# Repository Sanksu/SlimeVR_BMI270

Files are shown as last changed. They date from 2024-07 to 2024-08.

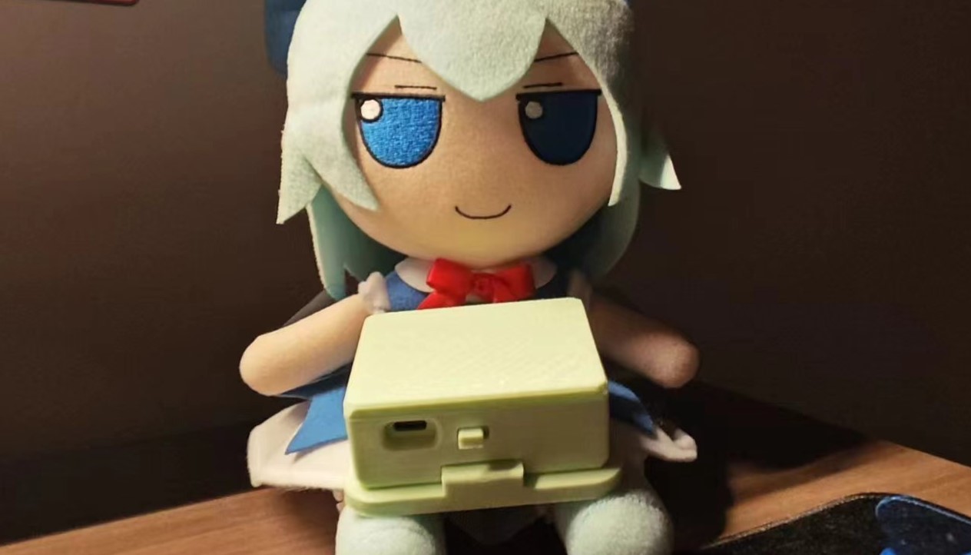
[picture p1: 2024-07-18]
IMG/cover.jpg

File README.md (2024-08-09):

## **SlimeVR_BMI270**


### **1. 什么是SlimeVR？**
SlimeVR是一组开放的硬件传感器和开源软件，有助于在虚拟现实中实现全身跟踪（FBT）。
- [官方文档](https://docs.slimevr.dev/)
- [l0ud/SlimeVR-Tracker-ESP-BMI270分支](https://github.com/l0ud/SlimeVR-Tracker-ESP-BMI270)

### **2. 介绍**
本项目由 ESP-12F + IP5306-CK + BMI270 组成，CH340K实现自动下载，采用LDO降压，提供3.3V供电

**官网对BMI270的介绍如下**：BMI270 是一款相对较新的实验性 IMU，用于 DIY SlimeVR。 它的性能似乎明显优于 BMI160，同时价格实惠。
外壳使用Fusion360设计外壳

### **3. 固件**
SlimeVR 固件的主分支尚不支持此BMI270，因此本项目使用[``` l0ud/SlimeVR-Tracker-ESP-BMI270 ```](https://github.com/l0ud/SlimeVR-Tracker-ESP-BMI270)分支

#### 3.1 **构建 SlimeVR 固件**
- 安装[CH340驱动](https://cdn.sparkfun.com/assets/learn_tutorials/8/4/4/CH341SER.EXE)
- VSCode安装PlatformIO IDE扩展

- 克隆[``` l0ud/SlimeVR-Tracker-ESP-BMI270 ```](https://github.com/l0ud/SlimeVR-Tracker-ESP-BMI270)分支并通过VSCode打开(在此期间VSCode会自动配置环境，请保持网络畅通)
- 在 ```platformio.ini``` 设置```DWIFI_CREDS_SSID```和```DWIFI_CREDS_PASSWD```
- 替换```src```/```defines.h```

```
#define IMU IMU_BMI270
#define SECOND_IMU IMU
#define BOARD BOARD_CUSTOM
#define IMU_ROTATION DEG_90
#define SECOND_IMU_ROTATION DEG_0

#define PRIMARY_IMU_OPTIONAL true
#define SECONDARY_IMU_OPTIONAL true

#define MAX_IMU_COUNT 1

#ifndef IMU_DESC_LIST
#define IMU_DESC_LIST \
    IMU_DESC_ENTRY(IMU,        PRIMARY_IMU_ADDRESS_ONE,   IMU_ROTATION,        PIN_IMU_SCL, PIN_IMU_SDA, PRIMARY_IMU_OPTIONAL,   PIN_IMU_INT) 

#endif

#define BATTERY_MONITOR BAT_EXTERNAL
#define BATTERY_SHIELD_RESISTANCE 180

#define PIN_IMU_SDA D2
#define PIN_IMU_SCL D1
#define PIN_IMU_INT D0
#define PIN_IMU_INT_2 D5
#define PIN_BATTERY_LEVEL A0
```
#### 3.2 **上传固件**
- 使用数据线连接
- 点击```PlatformIO:Upload```,等待烧录完成

### 4. **使用**
- 打开SlimeVR服务端，按提示操作

### 5. **其他**
BMI270的i2c地址是0x68(当SDO脚接地)/0x69(当SDO脚拉高)，SlimeVR源码中```MPU9250```/```BMI160```/```MPU6500```/```ICM20948```/```ICM42688```默认作为主传感器的i2c地址为0x68，我在画第一版的时候是将SDO脚拉高了，所以把```src```/```sensors```/```sensoraddresses.h```文件中的0x68与0x69做了替换，修改过的版本无需注意

###  6. **感谢**
- 主要电路参考[SlimeVR_BNO085](https://oshwhub.com/myzhazha/slimevr)，感谢

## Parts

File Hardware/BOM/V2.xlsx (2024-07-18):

No. | Quantity | Comment | Designator | Footprint | Value | Manufacturer Part | Manufacturer | Supplier Part | Supplier
1 | 6 | 22uF | C1,C2,C3,C4,C7,C8 | C0603 | 22uF | GRM188R61A226ME15D | muRata(村田) | C84419 | LCSC
2 | 4 | 10uF | C5,C6,C11,C12 | C0603 | 10uF | CL10A106KP8NNNC | SAMSUNG(三星) | C19702 | LCSC
3 | 4 | 100nF | C9,C10,C13,C17 | C0603 | 100nF | CC0603KRX7R9BB104 | YAGEO(国巨) | C14663 | LCSC
4 | 1 | 1uF | C15 | C0603 | 1uF | CL10A105KB8NNNC | SAMSUNG(三星) | C15849 | LCSC
5 | 1 | ZX-XH2.54-2PWT | CN1 | CONN-SMD_2P-P2.54_MEGASTAR_ZX-XH2.54-2PWT |  | ZX-XH2.54-2PWT | Megastar(兆星) | C7429671 | LCSC
6 | 1 | WAFER-SH1.0-4PWB | CN2 | CONN-SMD_4P-P1.00_WAFER-SH1.0-4PWB |  | WAFER-SH1.0-4PWB | XUNPU(讯普) | C3029343 | LCSC
7 | 2 | TS-1185-C-A-A-A | EN1,FLASH1 | SW-SMD_L4.0-W3.0-LS5.0-EH |  | TS-1185-C-A-A-A | XKB Connectivity(中国星坤) | C561518 | LCSC
8 | 2 | 1uH | L1,L2 | IND-SMD_L4.4-W4.2 | 1uH | APS04H20M1R0 | Coilank(驰兴电感) | C706859 | LCSC
9 | 2 | 19-217/GHC-YR1S2/3T | LED1,LED3 | LED0603-RD |  | 19-217/GHC-YR1S2/3T | EVERLIGHT(亿光) | C72043 | LCSC
10 | 2 | NCD0603R1 | LED2,LED4 | LED0603-RD_RED |  | NCD0603R1 | 国星光电 | C84263 | LCSC
11 | 2 | S8050 | Q1,Q2 | SOT-23-3_L2.9-W1.3-P1.90-LS2.4-BR |  | S8050 | FUXINSEMI(富芯森美) | C908252 | LCSC
12 | 2 | 5.1kΩ | R1,R2 | R0603 | 5.1kΩ | 0603WAF5101T5E | UNI-ROYAL(厚声) | C23186 | LCSC
13 | 1 | 2Ω | R3 | R0603 | 2Ω | 0603WAF200KT5E | UNI-ROYAL(厚声) | C22977 | LCSC
14 | 1 | 500mΩ | R4 | R0603 | 500mΩ | 0603WAF500LT5E | UNI-ROYAL(厚声) | C45312 | LCSC
15 | 3 | 10K | R5,R6,R7 | R0603 | 10K
16 | 7 | 10kΩ | R9,R10,R13,R14,R15,R16,R19 | R0603 | 10kΩ | 0603WAF1002T5E | UNI-ROYAL(厚声) | C25804 | LCSC
17 | 1 | 180kΩ | R11 | R0603 | 180kΩ | 0603WAF1803T5E | UNI-ROYAL(厚声) | C22827 | LCSC
18 | 2 | 0Ω | R12,R18 | R0603 | 0Ω | 0603WAF0000T5E | UNI-ROYAL(厚声) | C21189 | LCSC
19 | 1 | 44.2kΩ | R17 | R0603 | 44.2kΩ | 0603WAF4422T5E | UNI-ROYAL(厚声) | C23056 | LCSC
20 | 1 | 200kΩ | R20 | R0603 | 200kΩ | 0603WAF2003T5E | UNI-ROYAL(厚声) | C25811 | LCSC
21 | 1 | MK-12C02-G025 | SW2 | SW-SMD_MK-12C02-G025 |  | MK-12C02-G025 | G-Switch(品赞) | C778186 | LCSC
22 | 1 | IP5306 | U1 | ESOP-8_L4.9-W3.9-P1.27-LS6.0-BL-EP |  | IP5306 | INJOINIC(英集芯) | C181692 | LCSC
23 | 1 | BMI270 | U2 | LGA-14_L3.0-W2.5-P0.50-BR |  | BMI270 | Bosch(博世) | C2836813 | LCSC
24 | 1 | MP1601GTF | U3 | SOT-563-6_L1.6-W1.2-P0.5-LS1.6-BL |  | MP1601GTF |  | C9900006913 | LCSC
25 | 1 | WT8266-S5 ESP-12F | U4 | WIRELM-SMD_WT8266-S5-ESP-12F |  | WT8266-S5 ESP-12F | Wireless-tag(启明云端) | C784365 | LCSC
26 | 1 | CH340K | U5 | ESOP-10_L4.9-W3.9-P1.00-LS6.2-BL-EP |  | CH340K | WCH(南京沁恒) | C968586 | LCSC
27 | 1 | TYPE-C 16PIN 2MD(073) | USB1 | USB-C-SMD_TYPE-C-6PIN-2MD-073 |  | TYPE-C 16PIN 2MD(073) | SHOU HAN(首韩) | C2765186 | LCSC

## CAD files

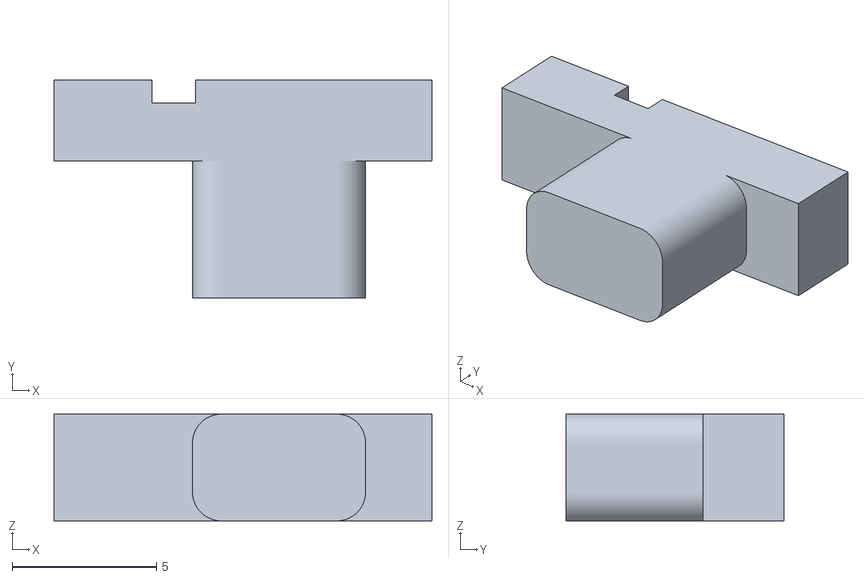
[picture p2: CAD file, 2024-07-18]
STLs/开关.stl
13.1 x 7.55 x 3.70

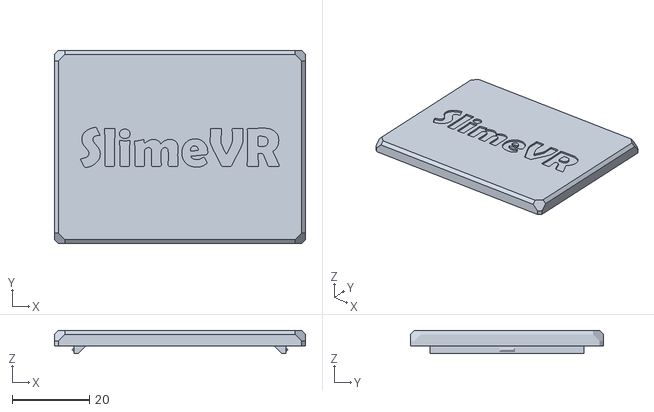
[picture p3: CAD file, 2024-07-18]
STLs/上壳.stl
65.0 x 50.0 x 6.00

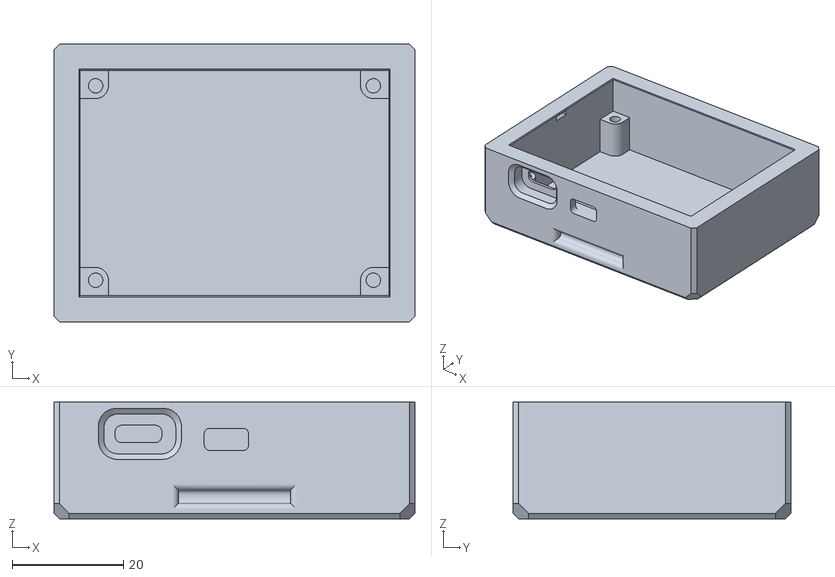
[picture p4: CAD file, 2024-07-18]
STLs/下壳.stl
65.0 x 50.0 x 21.0

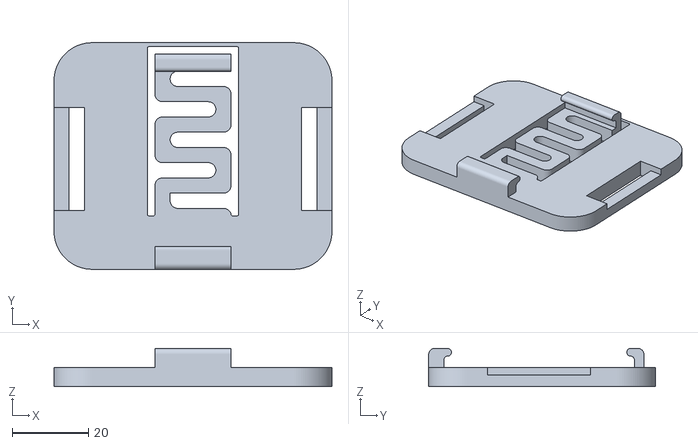
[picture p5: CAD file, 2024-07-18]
STLs/底座.stl
73.0 x 59.5 x 10.0

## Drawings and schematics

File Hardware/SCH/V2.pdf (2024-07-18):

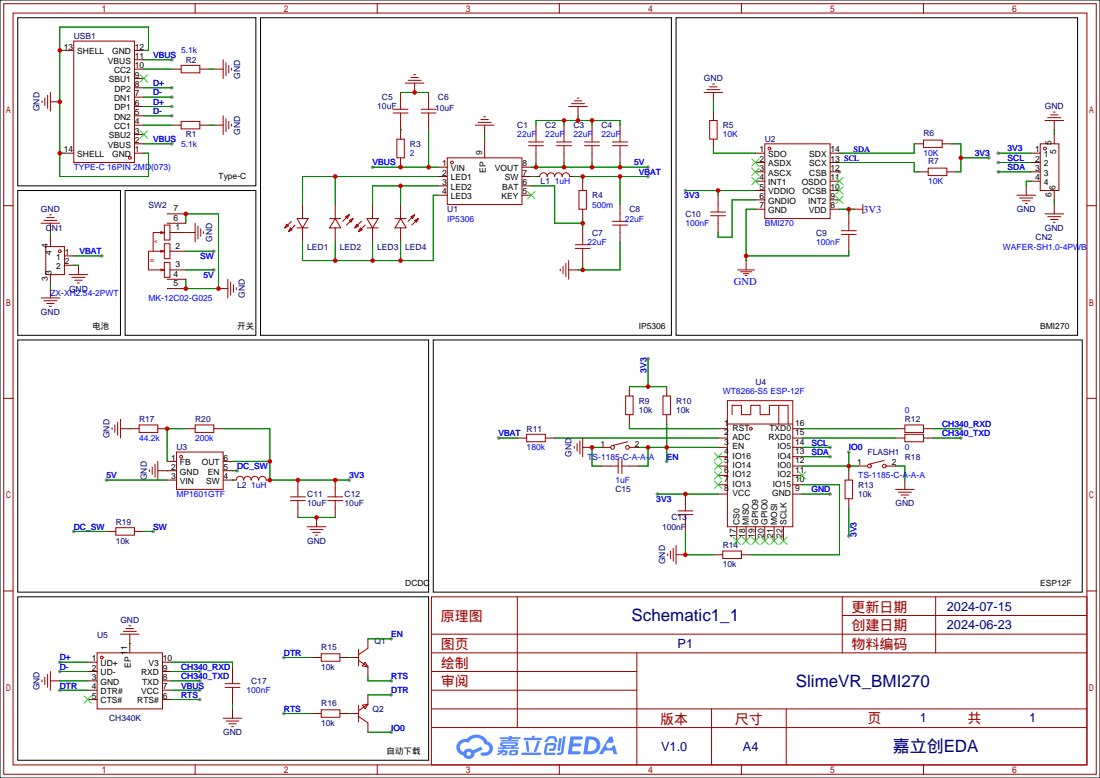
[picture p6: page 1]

OCSB 10 OSDO 11 CSB 12 SCX 13 SDX 14

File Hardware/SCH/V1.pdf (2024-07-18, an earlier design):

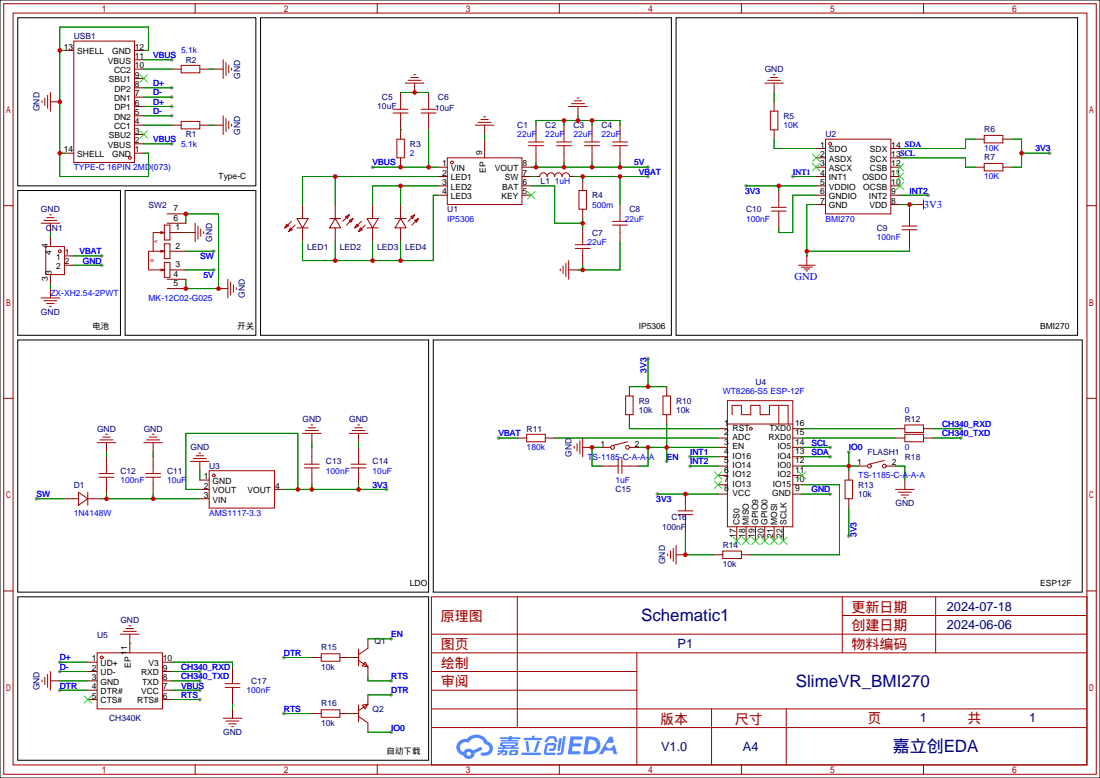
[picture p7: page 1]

OCSB 10 OSDO 11 CSB 12 SCX 13 SDX 14
